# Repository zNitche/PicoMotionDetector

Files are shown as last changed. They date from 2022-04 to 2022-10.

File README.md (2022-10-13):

### PicoMotionDetector

Raspberry Pi Pico powered motion detector integrated with [MotionDetectionAPI](https://github.com/zNitche/MotionDetectionAPI)

---

#### Parts
- 1x Raspberry Pi Pico
- 1x PIR HC-SR501
- 1x Circuit board
- 2x 100 uF capacitors
- 1x USB-C connector
- 1x L7805ABV 5V voltage regulator
- 1x ESP8266 (ESP-12E)
- Some gold pin connectors
- Some connecting wires

##### For better detection results (less false positives) 
Use 100 uF capacitor connected in parallel between VCC and GND of PIR sensor.
Additionally if input voltage is below 7V (L78 voltage dropout is 2V), power circuit using 5V power supply not using voltage stabilizer.

#### Setup
1. Set WiFi network and [MotionDetectionAPI](https://github.com/TheZodiaCC/MotionDetectionAPI) details in `consts.py`/`NetworkConsts` and `consts.py`/`DetectorConsts`
2. If needed tweak `ESP8266Consts` and / or `DetectorConsts` for PIN ids.

#### Media
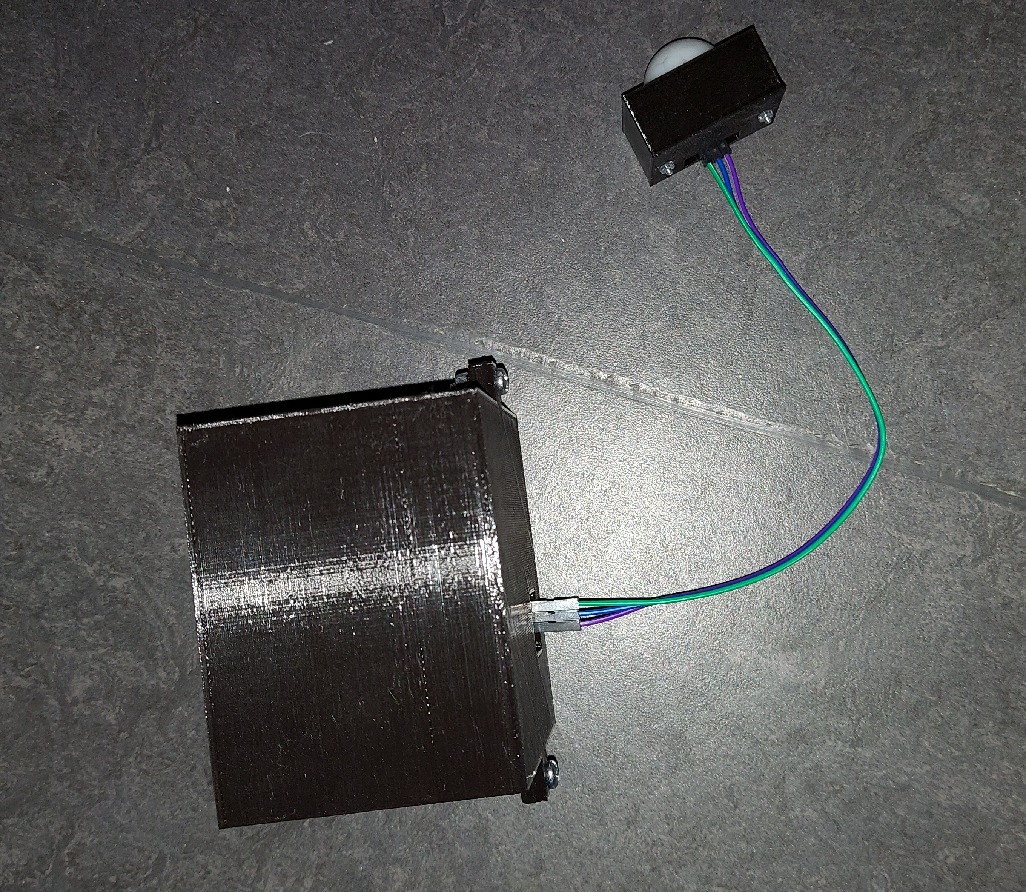
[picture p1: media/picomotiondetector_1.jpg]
picomotiondetector_1

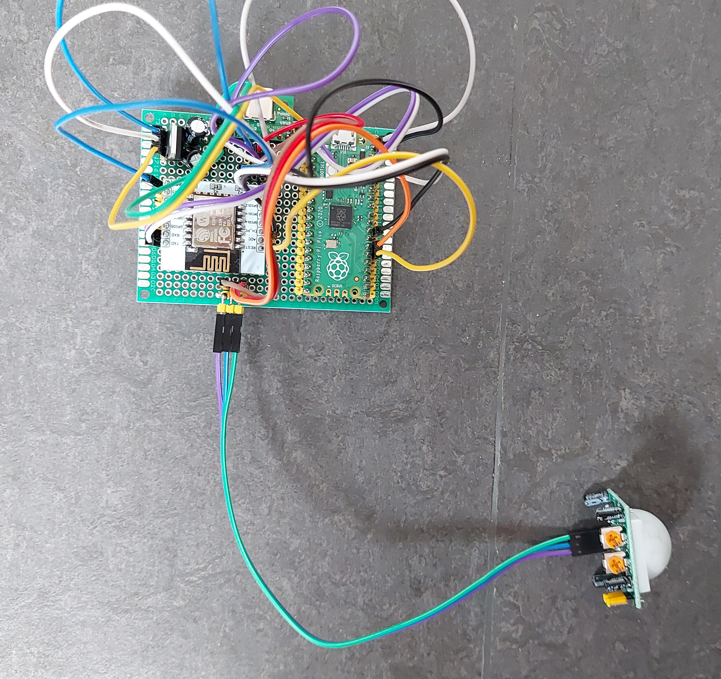
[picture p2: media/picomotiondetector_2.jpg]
picomotiondetector_2

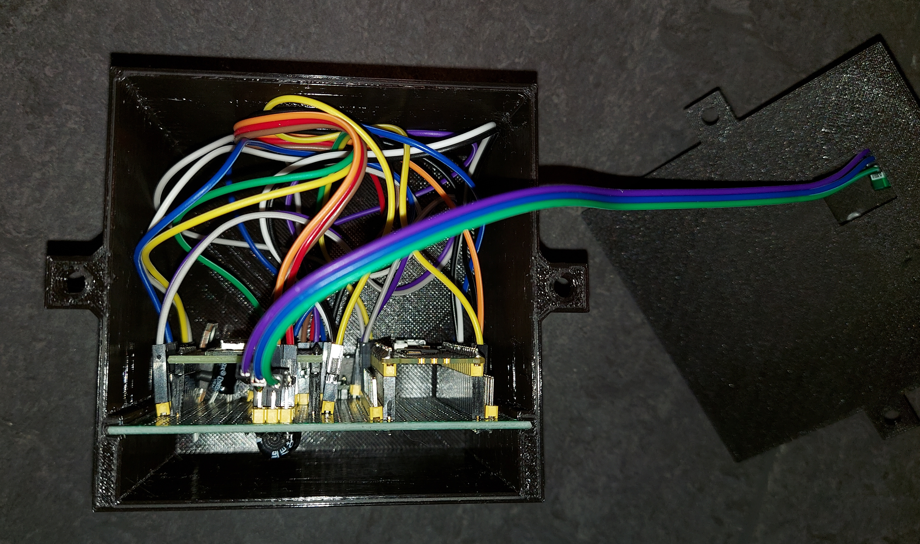
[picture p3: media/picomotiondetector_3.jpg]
picomotiondetector_3


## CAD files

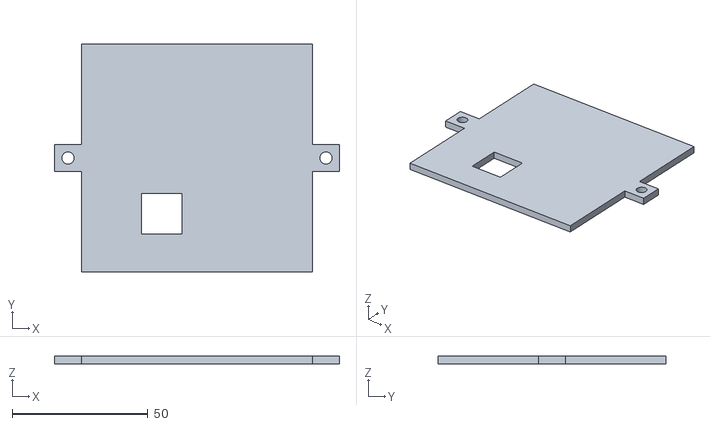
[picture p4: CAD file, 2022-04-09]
stl_parts/picomotiondetector_s_v1_cover.stl
105.0 x 84.0 x 3.00

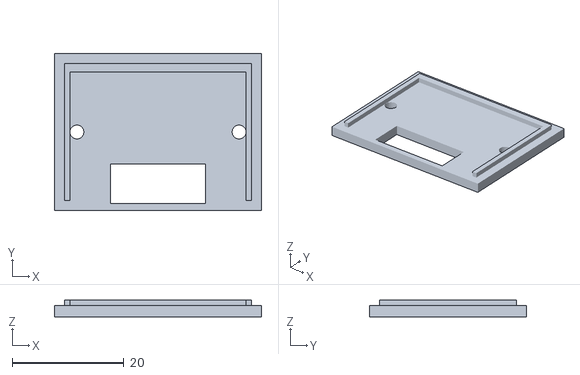
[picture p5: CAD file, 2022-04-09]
stl_parts/pir_rs501_cover_v2.stl
37.0 x 28.0 x 3.00

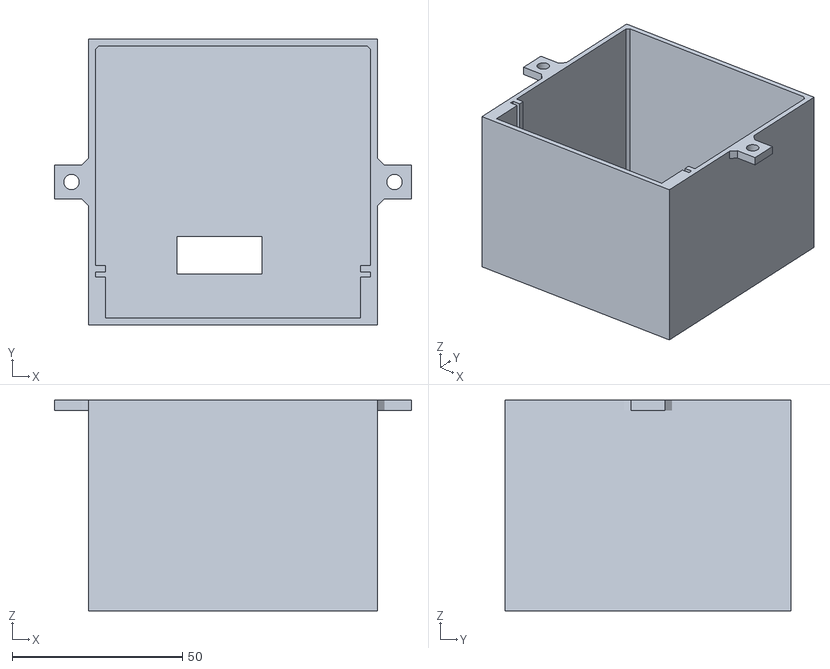
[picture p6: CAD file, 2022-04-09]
stl_parts/picomotiondetector_s_v1.stl
105.0 x 84.0 x 62.0

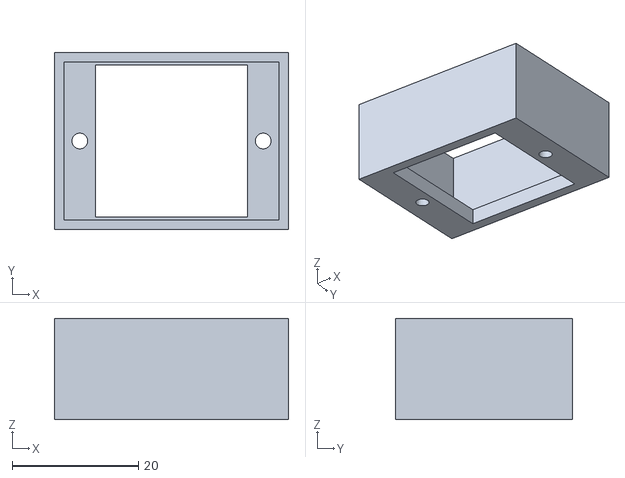
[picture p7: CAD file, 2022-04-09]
stl_parts/pir_rs501_holder_v2.stl
37.0 x 28.0 x 16.0

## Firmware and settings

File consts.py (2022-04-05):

class NetworkConsts:
    WIFI_PASSWORD = ""
    WIFI_SSID = ""

    API_IP = ""
    API_PORT = ""


class ESP8266Consts:
    STATE_PIN_ID = 22
    RESET_PIN_ID = 20

    UART_ID = 0
    UART_BAUDRATE = 115200


class DetectorConsts:
    SENSOR_PIN_ID = 21

    DETECTOR_NAME = ""

    API_ENDPOINT_PATH = "/api/notify"
    API_AUTH_TOKEN = ""

    UPDATE_RATE = 0.5

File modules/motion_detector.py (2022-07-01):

from machine import Pin
from modules.esp8266 import ESP8266
from consts import NetworkConsts, DetectorConsts
import time


class MotionDetector:
    def __init__(self):
        self.onboard_led = Pin(25, Pin.OUT)
        self.motion_sensor = Pin(DetectorConsts.SENSOR_PIN_ID, Pin.IN, Pin.PULL_DOWN)

        self.esp8266 = ESP8266()

        self.onboard_led.on()

        self.debug_mode = False

    def print_debug(self, message):
        if self.debug_mode:
            print(message)

    def init_wifi_connection(self):
        self.print_debug("Starting ESP8266...")

        if self.esp8266.check_module():
            self.print_debug("Connecting to network...")
            self.esp8266.connect_to_network(NetworkConsts.WIFI_SSID, NetworkConsts.WIFI_PASSWORD)

        else:
            self.print_debug("ESP8266 Startup...")
            self.esp8266.startup()

    def start_detector(self):
        self.print_debug("Starting Detector...")

        self.esp8266.startup()
        self.init_wifi_connection()

        self.mainloop()

    def mainloop(self):
        self.print_debug("Started Detector...")

        while True:
            if self.motion_sensor.value():
                self.print_debug("Movement detected...")

                if self.esp8266.check_connection():
                    self.print_debug("Connected with network...")

                    if self.esp8266.check_connection_with_host(NetworkConsts.API_IP):
                        self.print_debug("Connected with target API...")

                        self.esp8266.send_post(
                            '{"auth_token": "' + DetectorConsts.API_AUTH_TOKEN + '", "sensor": "' + DetectorConsts.DETECTOR_NAME + '"}',
                            NetworkConsts.API_IP, DetectorConsts.API_ENDPOINT_PATH, NetworkConsts.API_PORT)

                        self.print_debug("Sent payload...")

                else:
                    self.init_wifi_connection()

            time.sleep(DetectorConsts.UPDATE_RATE)

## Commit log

2022-03-31 increased uart timeout
2022-03-31 added prototype of detector class
2022-03-31 added support for PIR sensor
2022-04-04 fixed var name typo
    [motion_detector.py]
2022-04-09 added STL files for 3D printing
    [picomotiondetector_s_v1.stl, picomotiondetector_s_v1_cover.stl, pir_rs501_cover_v2.stl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]
2022-04-09 added images of the final device
2022-07-01 added printing messages about detector status for better debugging
